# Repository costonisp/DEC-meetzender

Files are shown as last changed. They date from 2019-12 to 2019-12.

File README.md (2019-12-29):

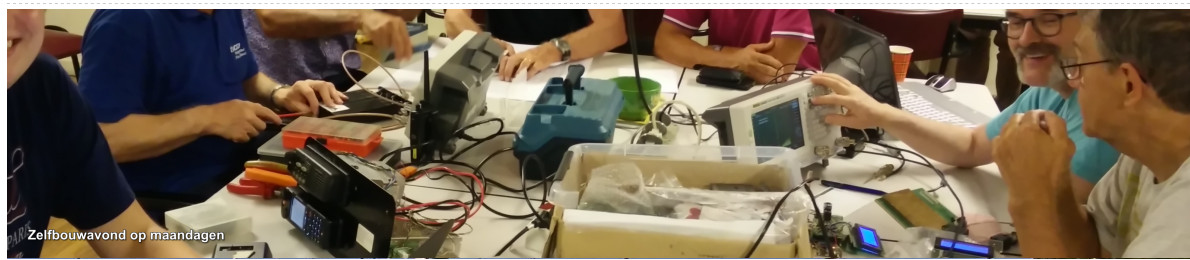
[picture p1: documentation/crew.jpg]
(https://www.pi4dec.nl/zelfbouw-meetzender/)

DEC meetzender met Si5351, en 150dB verzwakker, ontworpen door en voor **DEC Dordrecht**

Meeste aktieve bijdragen zijn geleverd door:

 - **Arnold PB0AIC :**  alle ontwerpen en printontwerpen voor: verzwakker, besturing en oscillator-I2C interface
 - **Mart PH0MH :** behuizing, draaibankwerkzaamheden voor oscillator behuizing en afscherming van de verzwakker.
 - **Arie PA3A :** software ontwerp.
 - **Coos PA0OOO :** software, co-ontwerp besturingsprint, documentatie.

__[Source Code](SourceCode/source_code.md)__

__[Besturings print](documentation/besturings_print.md)__

__[Verzwakker print](documentation/verzwakker_print.md)__

__[Si5351 oscillator + I2C isolator](documentation/Si5351%2Binterface.md)__

__[Behuizing](/documentation/behuizing.md)__

[**.**](https://github.com/costonisp/A/blob/master/node.md)

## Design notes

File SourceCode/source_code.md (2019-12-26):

__[SourceCode folder-view](/SourceCode)__

    Eenvoudigste is om de (meest recente) zipfile hieronder aan te klikken. 
    De [download] knop staat dan aan de rechter-zijde, naast de [history] knop.
    Plaats de uitgepakte zip-file in de Arduino sketch folder, waarna het compileren
    en uploaden naar een Mega2560 eenvoudig moet lukken.

    Zorg er wel voor dat een recente versie van de "Etherkit Si5351 by Jason Milldrum"  geinstalleerd is.

__[**Versie 3112.zip** : ](/SourceCode/Meetzender_v3112.zip)__ (december 2019)

   [Handleiding v3112](Handleiding3112.txt)
   
    Deze versie ondersteund diverse menu's, waardoor een verhoogd gebruiksgemak.
    Via menu kan een correctiefactor worden ingevoerd waarmee de afwijking van het 
    referentie Xtal op de oscillator module kan worden gecorrigeerd.
    Instelbaar Hamband menu, keuze van voorgeprogrammeerde frekwenties/golflengtes.
    Instelbare harmonische factor die de maximale aangegeven frekwentie bepaalt.
    Voor het geval dat 0dBm uitgangsvermogen te laag is kan via een menu tijdelijk 
    het uitgangsvermogen verhoogd worden tot ca +12 dBm. (Drive 2, 4, 6 of 8 mA)

__[Versie 085 CLK1 dec.zip : ](/SourceCode/Meetzender_0_85_CLK1_dec.zip)__(2018)

    >Deze versie is versie 085 aangepast aan de recente besturingsprint.
    Het signaal staat op CLK1, de middelste SMA connector.
    LCD display gebruikt pin 44 en 46, daardoor is pin 50 t/m 53 bruikbaar als SPI bus.

__[Versie 085.zip : ](/SourceCode/Meetzender_0_85.zip)__(2017)

    Dit is de oorspronkelijke versie geschreven door Arie PA3A.
    Werkt niet meer met de meest recente besturingsprint.
    LCD display gebruikt Arduino pin 50 en 52, waardoor de SPI bus geblokkeerd is.

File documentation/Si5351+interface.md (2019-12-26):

[//]: # (Table-A with 3-columns/5-lines, table-B with 2-columns/1-line)

## Si5351 Oscillator Board met  Bidirectionele Dual I2C Isolator:

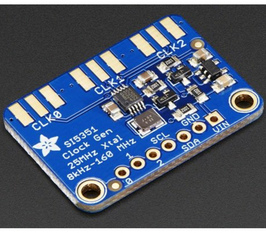
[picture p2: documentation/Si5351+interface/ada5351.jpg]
 | 
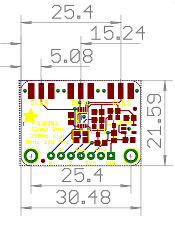
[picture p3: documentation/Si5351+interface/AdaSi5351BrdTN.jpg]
 | 
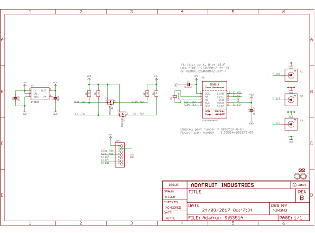
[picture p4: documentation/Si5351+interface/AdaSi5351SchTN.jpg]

--- | --- | ---
**Si5351 oscillator board** | **board layout** | **schema Si5351 board**
  |   | 
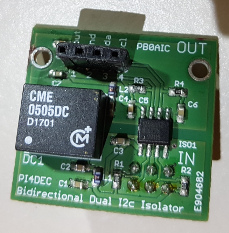
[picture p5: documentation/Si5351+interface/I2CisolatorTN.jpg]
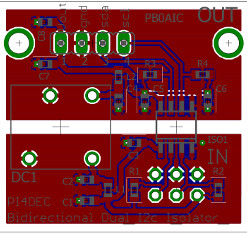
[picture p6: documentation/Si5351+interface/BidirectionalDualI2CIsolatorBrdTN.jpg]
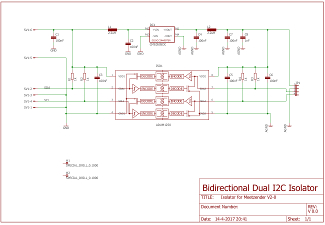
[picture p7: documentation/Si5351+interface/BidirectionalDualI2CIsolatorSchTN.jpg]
 |   | 
**I2C isolator board**  | **board layout** | **schema dual I2C isolator**

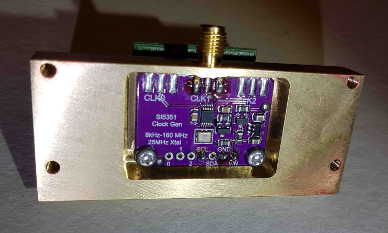
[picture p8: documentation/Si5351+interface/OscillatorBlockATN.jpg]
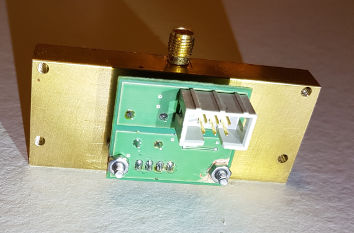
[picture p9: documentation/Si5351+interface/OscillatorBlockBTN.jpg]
 | 
---- | ----
 **Oscillator board in messing behuizing** | **I2C board op achterzijde behuizing**

Het AdaFruit Si5351 oscillator-board is in een massief messing blok gemonteerd en dit word op de messing afscherming van de verzwakker print geschroefd. 
Aan de achterkant van de oscillator-module is het I2C Isolator board gemonteerd. 
Om hf-lekkage te vermijden is dit board van eigen DC-DC converter voorzien. De I2C isolatie is met een <a href="Si5351+interface/ADUM1250_1251.pdf"> ADUM1250 </a> isolatorIC .
 
De oscillator module word met een bandkabel op de besturingsprint aangesloten.

Met een semi-rigid RG402 coax-kabel is de oscillator module op de verzwakker module aangesloten.
Daardoor kan het signaal niet via I2C, voedings leiding of door een niet volledig hf-dichte coax naar buiten lekken.
Op deze manier is het mogelijk om het signaal tot -145dBm te verzwakken.

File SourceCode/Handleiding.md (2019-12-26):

Coos, [18.12.19 20:46]
Gebruiksaanwijzing voor de meetzender software V.3012

**********************************
*
* -------- Display -----------
* regel1: f=  432.260.000 kHz
* regel2:  3e harmonic -9.5 dB
* regel3: L= - 73 dBm  xxxxxxx 
* regel4:      50  uV S9 + 0dB
* ----------------------------
*
*
*         Draaischakelaars:
*    S1         S2         S3
*   Level      N.C.    Frekwentie
*
*
*           Drukknoppen:
*   S4      S5      S6      S7 
* Store    Get   HamBand  Config
* waarde  waarde   Menu    Menu
*
**********************************

(dubbel)Functies van de knoppen:

S1 draaien om verzwakking in te stellen, op regel3,
   regel4 geeft de uitgangsspanning in mV, uV of nV 
   en de S-schaal van  S9+73dB tot S0-23dB
   drukken keuze 0, -33, -73, -109, -127, -140 dB

S3 draaien voor continue frekwentie instellen
   drukken onm de digit (stap) te kiezen

S4 Store waarde, slaat level en Frekwentie op in EEprom 

S5 Get waarde, haal opgeslagen Level en Frekwentie uit EEprom

S6 HamBand Menu, Met S3 draaiknop kies je een HamBand

S7 Dubbele functie, kort drukken kom je in het configuratie menu
   Lang drukken (>3 seconden) een soft reset indien nodig.

Configuratie Menu, met S3 draaiknop de optie kiezen
1: calibratie xxx  ppm
2: Si5351 fMax <150 MHz
3: Harmonic factor 3-15
4: Drive Output 2,4,6,8 mA
5: Zet waarden in EEprom
   Met S1 de optie bevestigen en draaien voor waarde veranderen.
   Opnieuw S1 op de waarde te bevestigen.

1: calibreren van het 25MHz referentie Xtal 
Calibratie van het referentie Xtal frequentie, correctie in ppm
S1 drukken en dan met S1 de correctiewaarde instellen
S1 opnieuw drukken om de waarde te bevestigen

2: Si5351 fMax
Default waarde is 150MHz, kan met 25MHz stappen tot 300MHz.
N.B. door een beperking van de etherkit library kan bij frekwenties
vanaf 150 MHz de output willekeurig uitvallen, deze optie is voor test.
Met S1 kiezen en bevestigen.

3: Harmonic factor naar keuze 1, 3e, 5e, 7e, 9e, 11e, 13e, 15e
Te activeren met S1, draaien voor waarde en opnieuw S1 drukken om te bevestigen.
Bij 1 kan de meetzender tot 150MHz, met 3 tot 450 MHz enz.
1e-150 / 3e-450 / 5e-750 / 7e-1050 / 9e-1350 / 11e-1650 / 13e-1950 / 15e-2250MHz
Indien van toepassing staat op regel 2 de harmonische met de correctie.
Harmonischen van een blokgolf zijn minder sterk dan de grondgolf.
3e harminische is 1/3 in spanning, wat gelijk staat aan -9.5dB
5e=-14dB  7e=-17dB  9e=-19dB 11e=-21dB 13e=-22.5dB 15e=-23.5dB
N.B. deze waarden zijn afgerond op 0.5dB (onnauwkeurigheid +/-0.25dB
Deze waarde moet van de aangegeven waarde afgetrokken worden om het juiste niveau v/d harmonische te berekenen. 
B.v. L=-33dB en 3e harm=-9.5, dan is niveau (-33 -9.5) = -43.5dB. 
De grondtoon is ook aanwezig op -33dB, net als alle harmonischen aanwezig zijn met een afnemend niveau.
Dat is onvermijdelijk met een ongefilterde blokgolf.
 
4: Si5351 Drive Output kan ingesteld worden, default waarde = 2mA. 
Daarop is de meetzender geijkt. Tijdelijk kan er een grotere Drive output gekozen worden, op regel 3 bij xxxx wordt de correctie waarde in dB gezet.
4 mA = +3dB / 6 mA = + 9.5 dB / 8 mA = +12 dB op te tellen bij het niveau

5: Zet waarden in EEprom
Door S1 te drukken staat op regel 3 Level knop opslaan en regel 4 annuleren andere knop,
Door opnieuw S1 te drukken worden de Referentie correctie (ppm) en de harmonische opgeslagen in EEprom. 
Drive mA en fMax van Si5351-chip worden niet opgeslagen, zodat bij een koude start of reset de Maximale frekwentie 150 MHz is en de Drive 2 mA bedraagt.

Opnieuw drukken van S7, verlaat het configuratie menu.

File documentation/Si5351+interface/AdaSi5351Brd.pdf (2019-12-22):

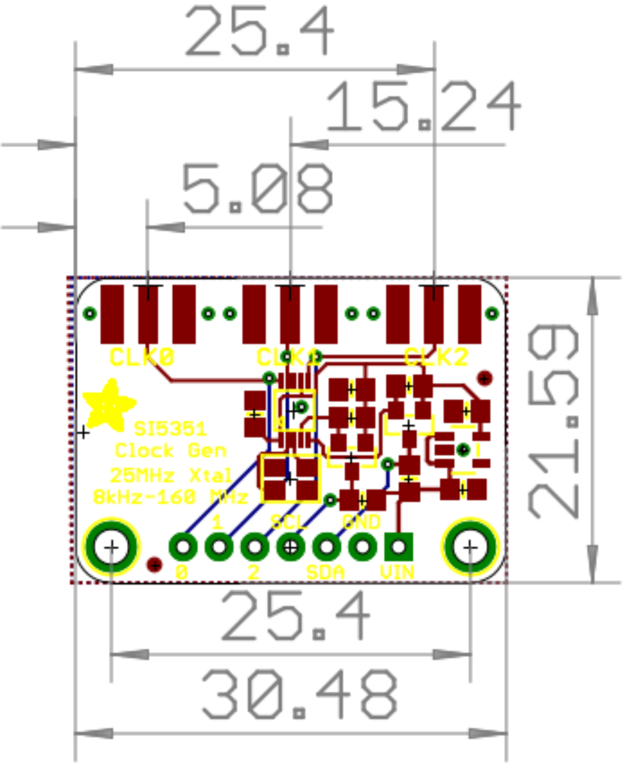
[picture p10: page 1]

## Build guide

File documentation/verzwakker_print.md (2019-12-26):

## VERZWAKKER PRINT :

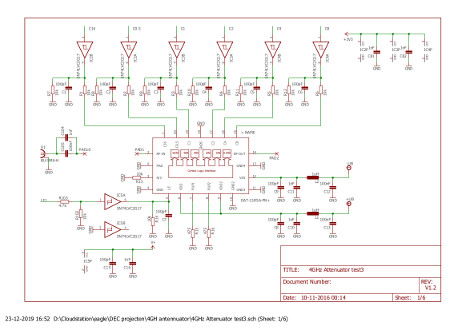
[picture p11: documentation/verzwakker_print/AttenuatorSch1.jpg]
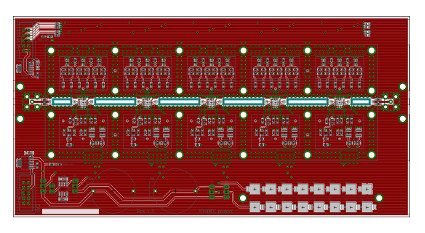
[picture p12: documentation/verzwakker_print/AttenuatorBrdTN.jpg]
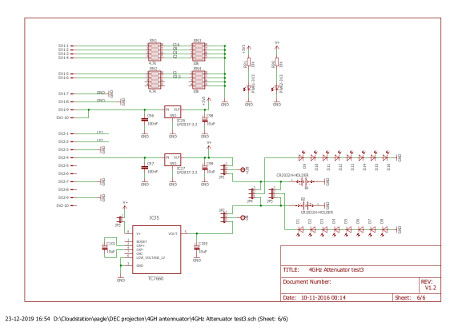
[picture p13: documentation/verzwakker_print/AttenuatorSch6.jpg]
 |     |     
--------------------------------------------- | --- |  --------------------------------------------
**5x Digitale stap verzwakker** | **Board layout**  | **Power Supply verzwakker**
|  | 
|  |

De verzwakker module bestaat uit 5 identieke deelverzwakkers. Iedere deelverzwakker bestaat uit een [DAT-31R5A-PN](verzwakker_print/DAT-31R5A-PN.pdf)  digitale stap verzwakkers van Mini Circuits met daarbij behorende stuur logica. Ieder IC met componenten zit op het PCB in een eigen omgeving. Als afscherming dienen twee uitgefreezde messing platen die boven en onder over de PCB gemonteerd worden. Daardoor ontstaan 5 kleine rf-dichte kamertjes. De koppeling tussen de 5 verzwakkers gebeurt met kleine stukjes 50 ohm RG402 kabel.

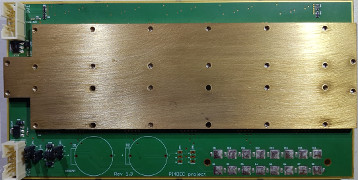
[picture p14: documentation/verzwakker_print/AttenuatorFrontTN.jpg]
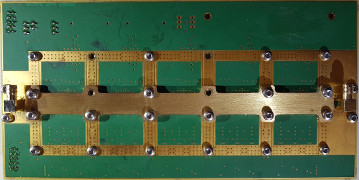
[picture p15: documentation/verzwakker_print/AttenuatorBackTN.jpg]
 |    

Een enkele verzwakker is 6-bit met een resolutie van 0.5dB, zodat per chip max -31.5dB is in te stellen. Met 5 deelverzwakkers in serie kan zodoende maximaal -157.5dB ingesteld worden. In de praktijk blijkt dat de bruikbare grens bij 145dB verzwakking ligt. Dit wordt veroorzaakt doordat een zeer klein deel van het rf-signaal toch weg kan lekken

De verzwakker kan tot minstens 3000 MHz goed werken. Voor de meetzender ligt de praktische grens iets boven 1000 MHz.
Dit komt door de schakeltijden in de Si5351 oscillator die een blokgolf produceerd waarbij harmonischen worden gebruikt om boven 150 Mhz te komen. De 150 MHz wordt bepaald door de etherkit library, die boven 150 MHz onvoorspelbaar gedrag vertoond, de Si5351 chip zelf kan tot ca. 250 MHz stabiele signalen geven

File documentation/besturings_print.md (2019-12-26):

[//]: # (Table with 3-columns/7-lines)

## BESTURINGS PRINT :

De Besturingsprint is een 4-laags PCB. 
De signaal verbindingen liggen opgesloten tussen een massa vlak en een Vcc vlak, zodat stoorstraling geminimaliseerd wordt.

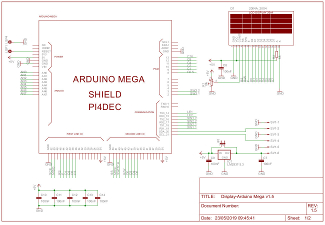
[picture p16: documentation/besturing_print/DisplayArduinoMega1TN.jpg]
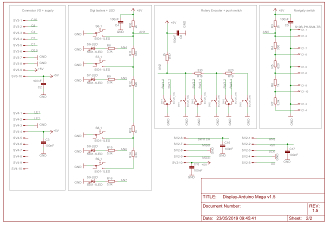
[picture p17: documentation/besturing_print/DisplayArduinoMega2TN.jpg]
 | **+** |  
--------------------------------------------- | --- |  -----------------------------------------------
**ArduinoMega2560 + Display + I2C-connector** |     | **Drukknoppen + Rotary schakelaars + connectors**
  |     |  
  |     | 
  |     | 
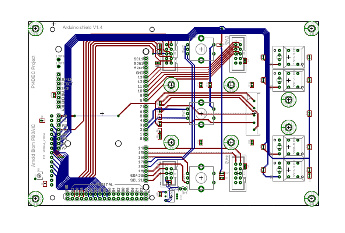
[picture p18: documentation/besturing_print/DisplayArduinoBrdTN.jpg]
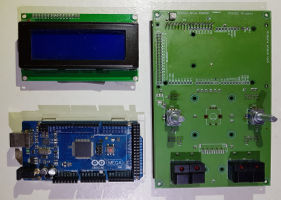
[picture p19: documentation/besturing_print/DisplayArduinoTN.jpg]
 |**-** | 
  **PCB layout** *( inner layers )* |     |   **module's v/d besturingsprint**
  
**Headers :** voor een full-size Arduino Mega 2560

**Header  :** voor een Display LCD2004

**Boxed Headers :**

 -  SV1 :  6-polig connector (sda-scl) + voeding voor dual I2C isolator board
 -  SV2 : 10-polig connector + voeding van SPI-bus
 -  SV3 : 10-polig data stuursignaal verzwakker print
 -  SV4 : 10 polig latch stuursignaal verzwakker print

**Schakelaars :**

 -  tact-switches:  S6, S7, S8 en S9  met Led's
 -  rotary-swiches: SW1 en SW2  met drukschakelaar S1 en S2

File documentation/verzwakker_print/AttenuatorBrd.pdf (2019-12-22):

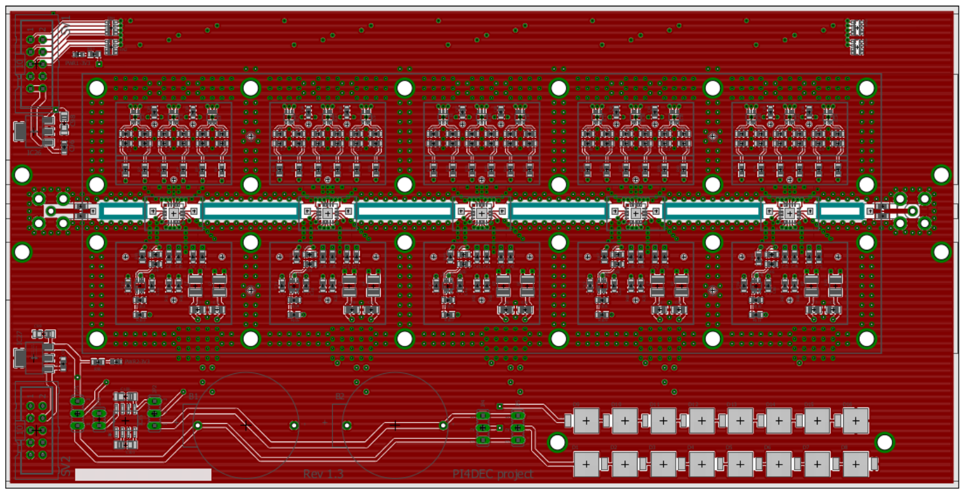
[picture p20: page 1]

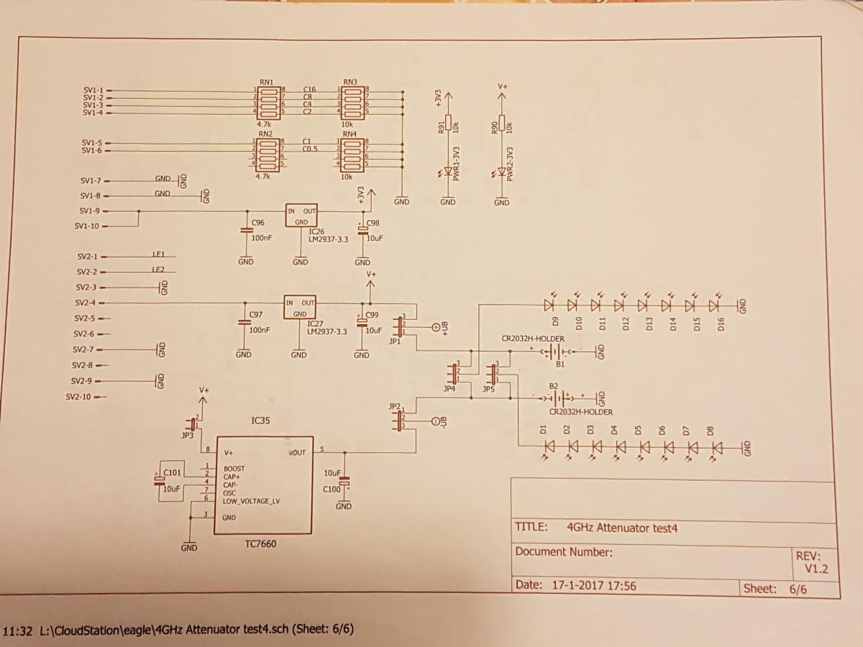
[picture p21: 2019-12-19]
documentation/verzwakker_print/AttenuatorPower.jpg

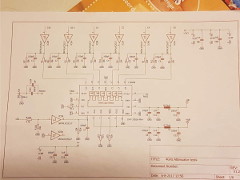
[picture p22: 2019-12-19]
documentation/verzwakker_print/AttenuatorTN.jpg

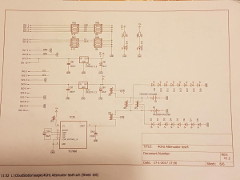
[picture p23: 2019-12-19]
documentation/verzwakker_print/AttenuatorPowerTN.jpg

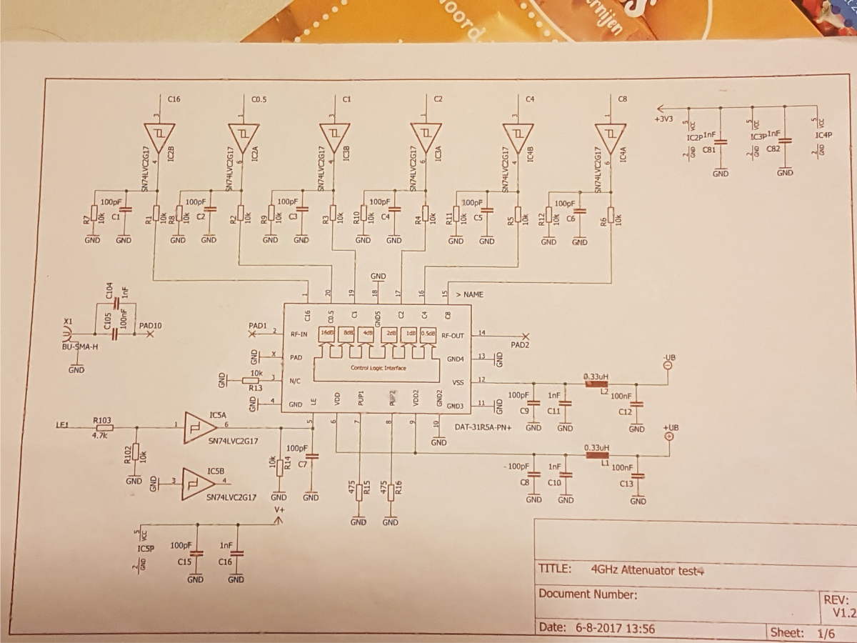
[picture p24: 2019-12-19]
documentation/verzwakker_print/Attenuator.jpg

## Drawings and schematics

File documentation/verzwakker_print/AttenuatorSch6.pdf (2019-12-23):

# GND ¹⁰k

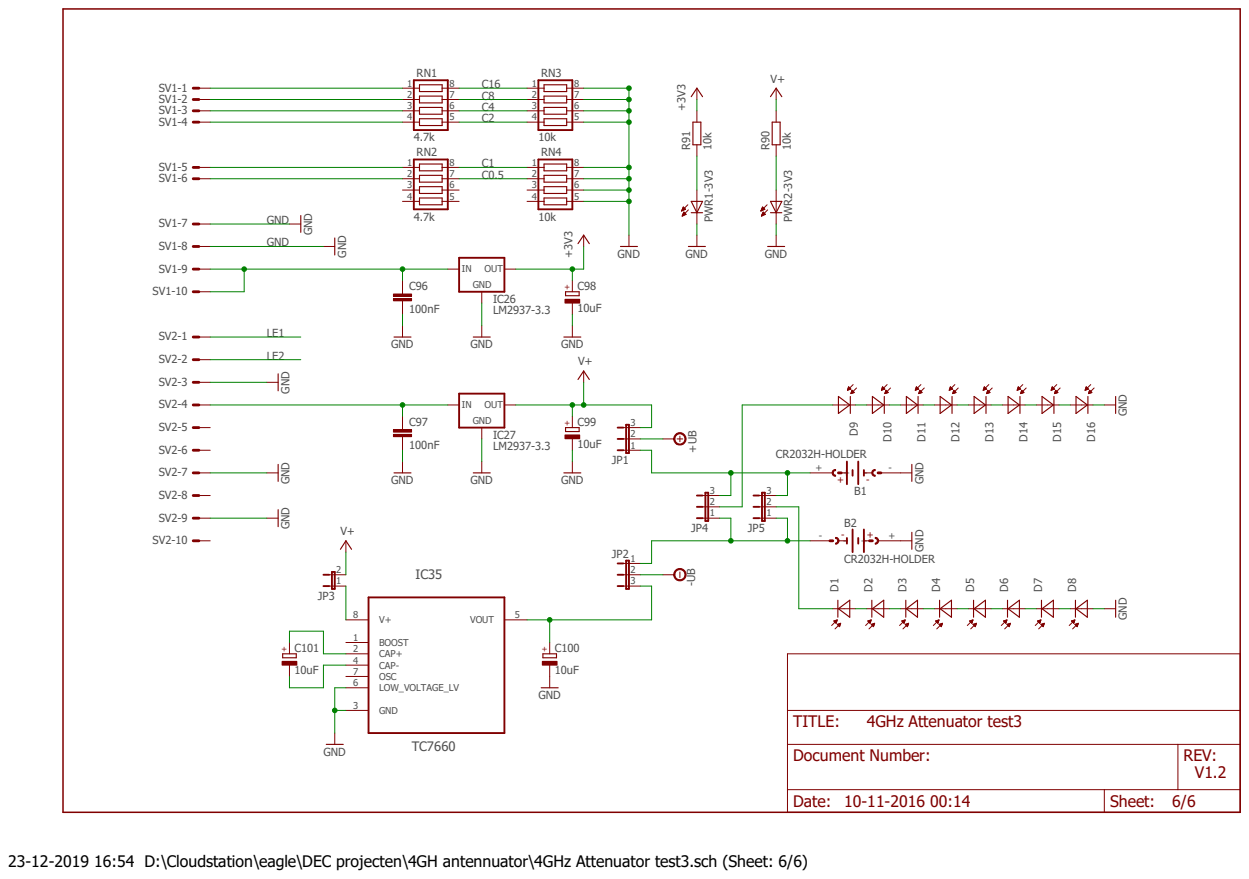
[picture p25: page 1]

7 C8 2 | 7
6 C4 3 | 6

7 C0.5 2 | 7

Document Number: | REV: V1.2

Date: 10-11-2016 00:14 | Sheet: 6/6

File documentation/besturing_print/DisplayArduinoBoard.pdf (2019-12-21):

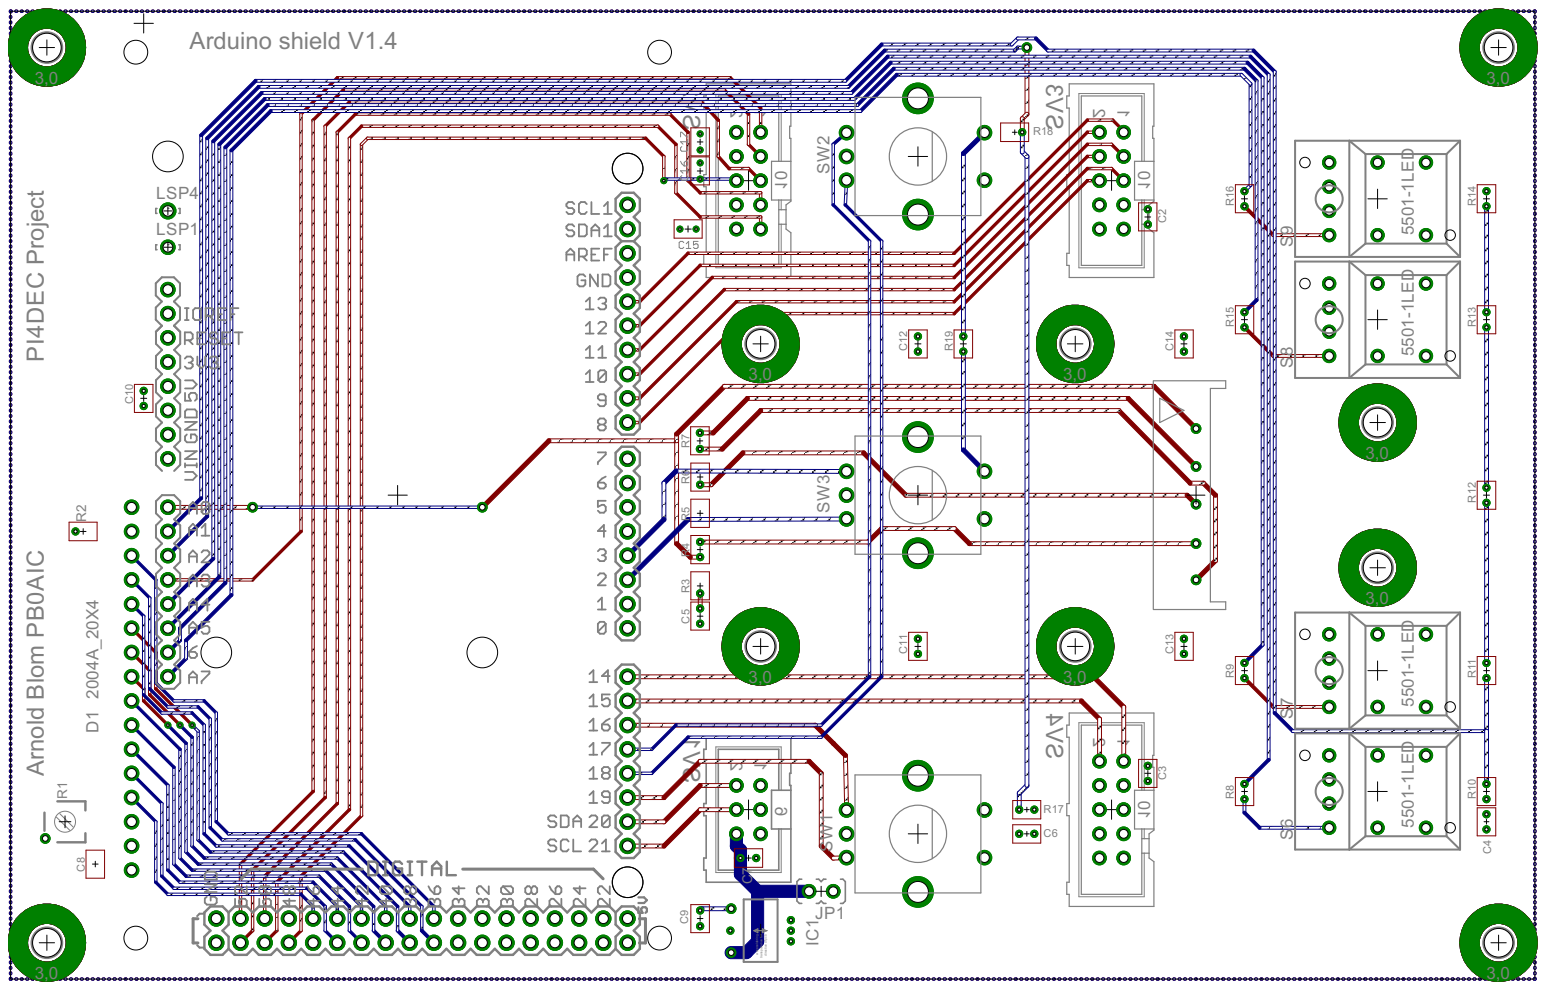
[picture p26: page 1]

SV3 SV4 SV1 SV2 10 21 10 21 21 6 10 21 Arduino shield V1.4 Arnold Blom PB0AIC PI4DEC Project D1 R2 SW1 SW2 SW3 R3 R4 R5 R6 R7 S6 S7 R8 R9 R10 R11 R12 R13 R14 S8 S9 R15 R16 R1 R17 R18 C2 C3 C4 C5 C6 C C7 8 LSP1 LSP4 IC C19 C10 C11 C12 C13 C14 JP1 R19 2004A_20X4 5501-1LED 5501-1LED 5501-1LED 5501-1LED 3,0 3,0 3,0 3,0 3,0 3,0 3,0 3,0 3,0 3,0 direction of pcb transportation for wavesoldering

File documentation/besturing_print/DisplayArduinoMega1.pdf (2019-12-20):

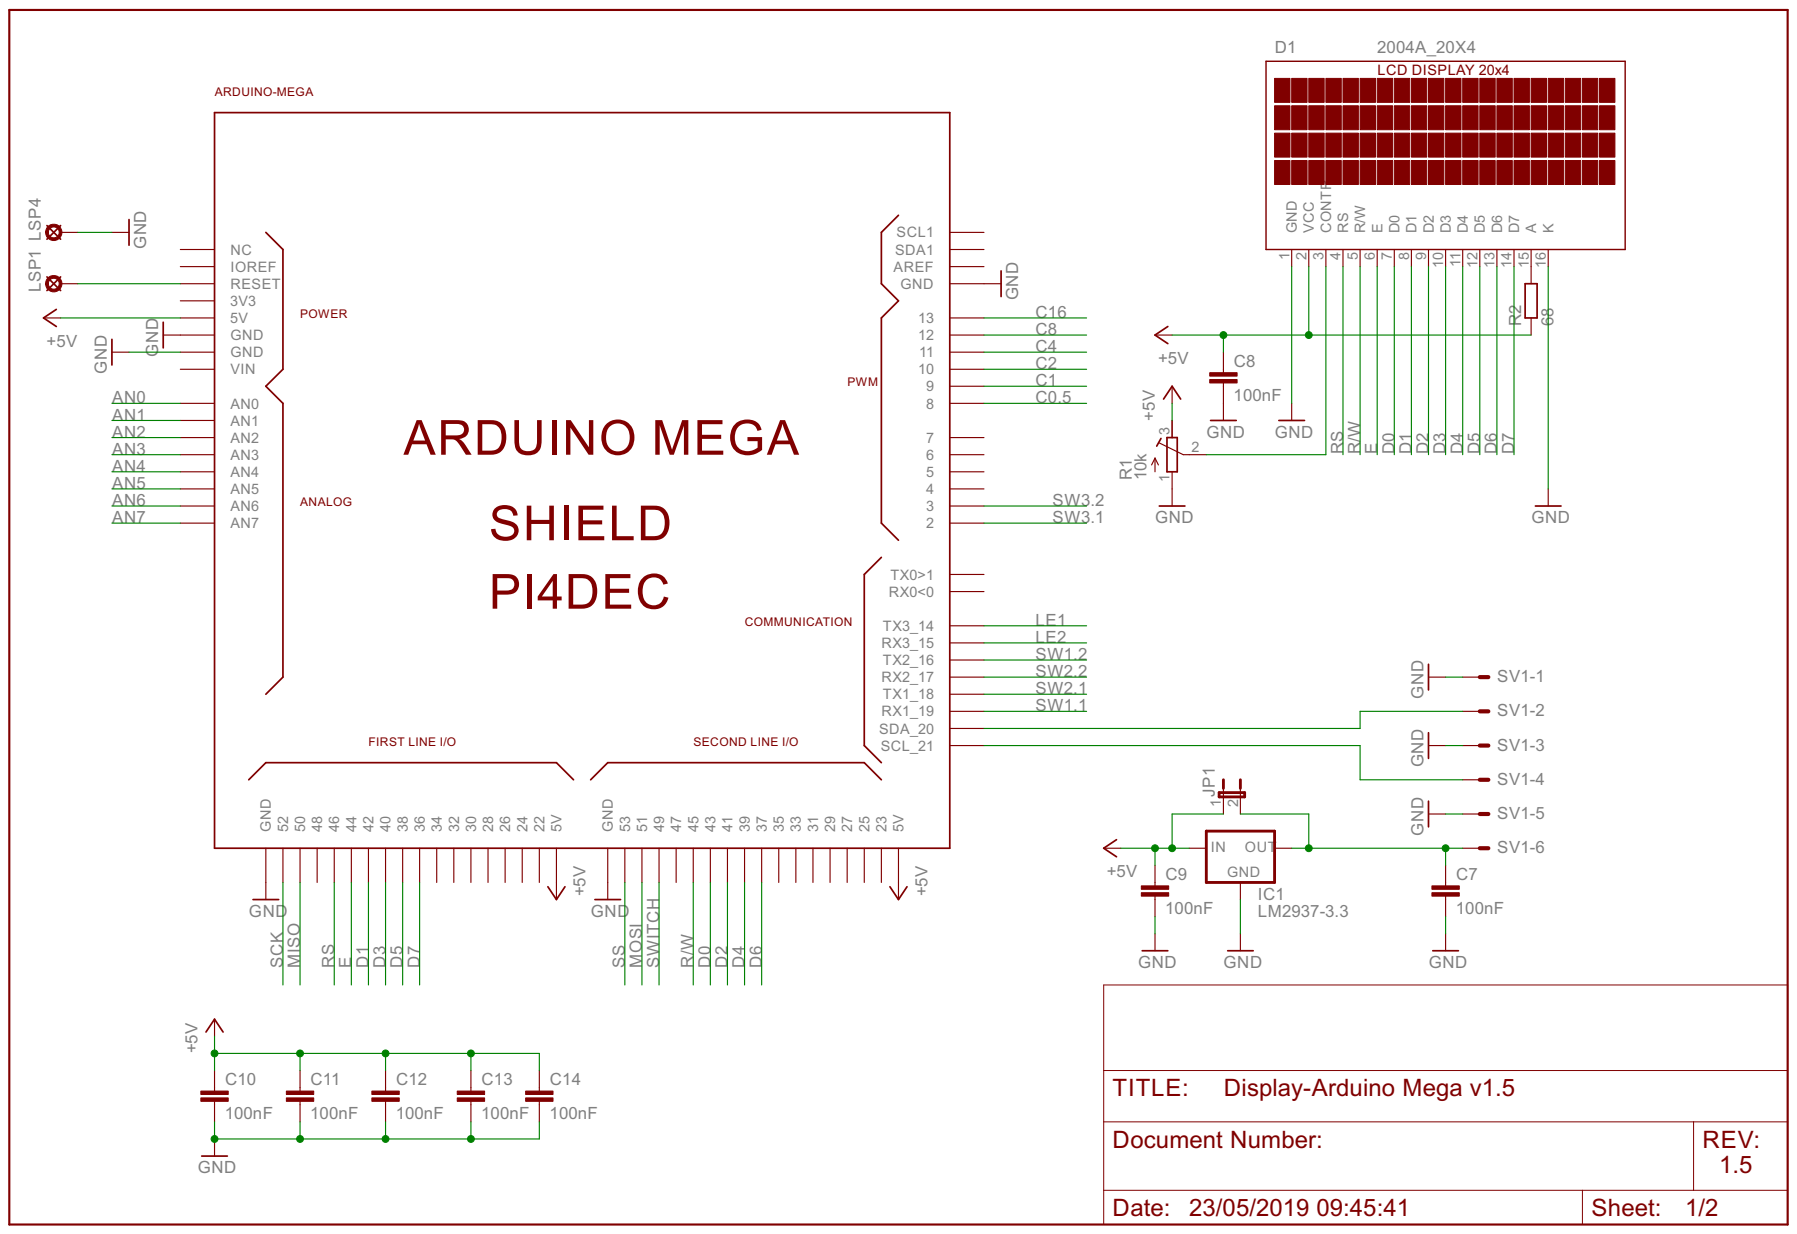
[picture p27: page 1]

LCD DISPLAY 20x4 ARDUINO MEGA

Document Number: | REV: 1.5

Date: 23/05/2019 09:45:41 | Sheet: 1/2

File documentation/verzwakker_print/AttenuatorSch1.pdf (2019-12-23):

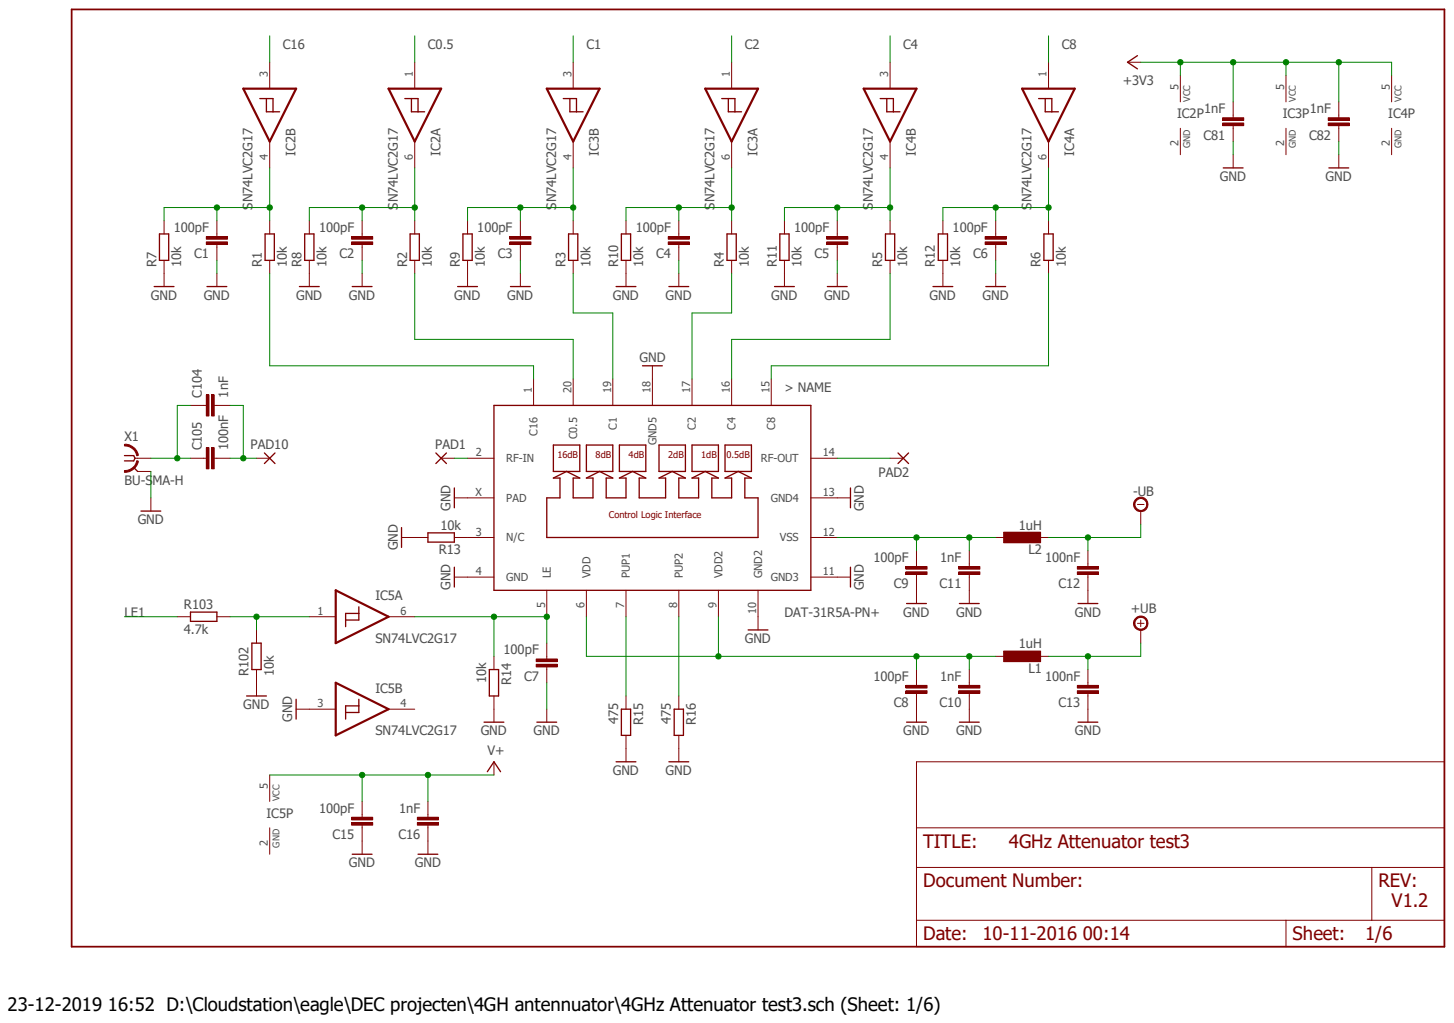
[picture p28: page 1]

Document Number: | REV: V1.2

Date: 10-11-2016 00:14 | Sheet: 1/6

23-12-2019 16:52 D:\Cloudstation\eagle\DEC projecten\4GH antennuator\4GHz Attenuator test3.sch (Sheet: 1/6)

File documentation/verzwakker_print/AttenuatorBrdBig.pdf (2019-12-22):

22-12-2019 22:29 f=1.40 D:\Cloudstation\eagle\DEC projecten\4GH antennuator\4GHz Attenuator test3.brd ¹⁰

## PWR1-3V3

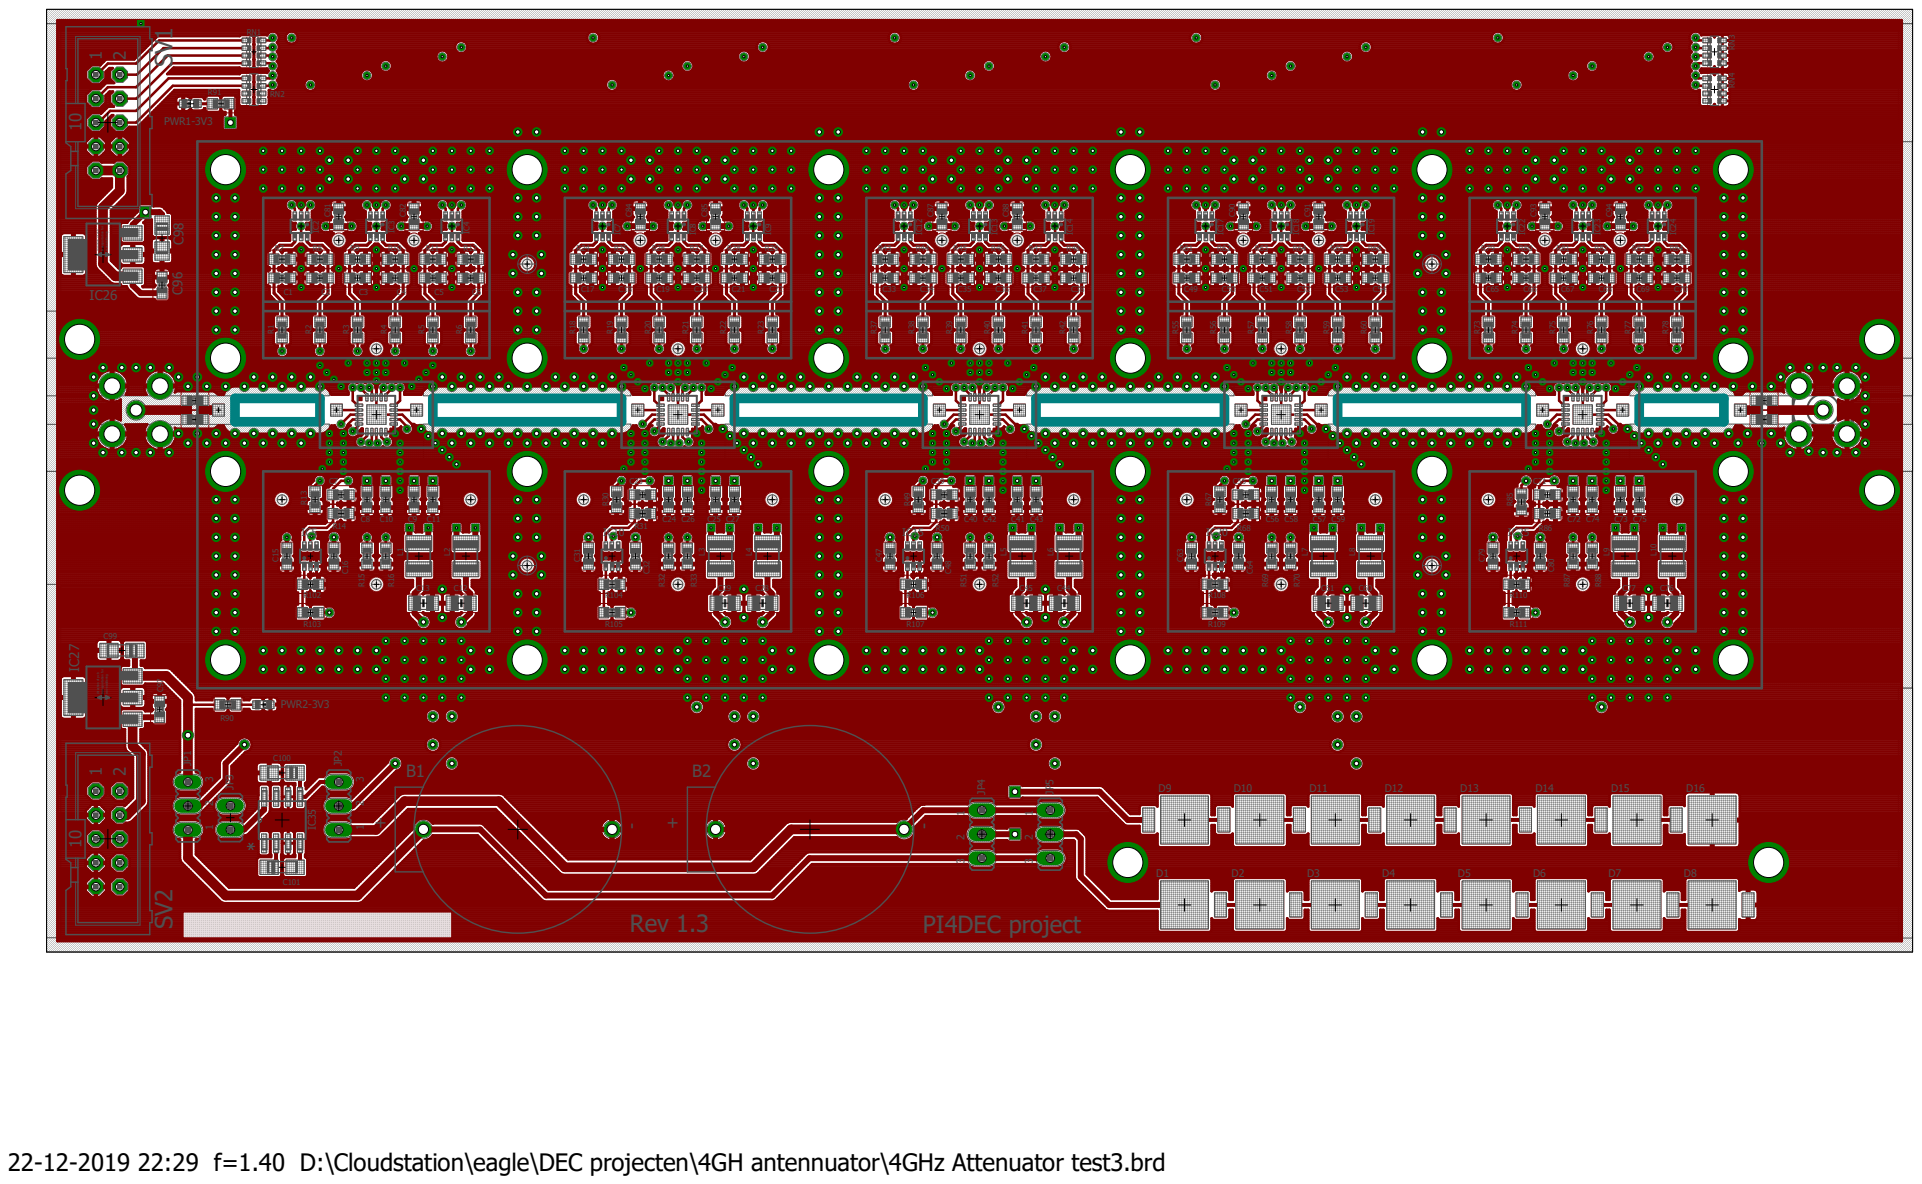
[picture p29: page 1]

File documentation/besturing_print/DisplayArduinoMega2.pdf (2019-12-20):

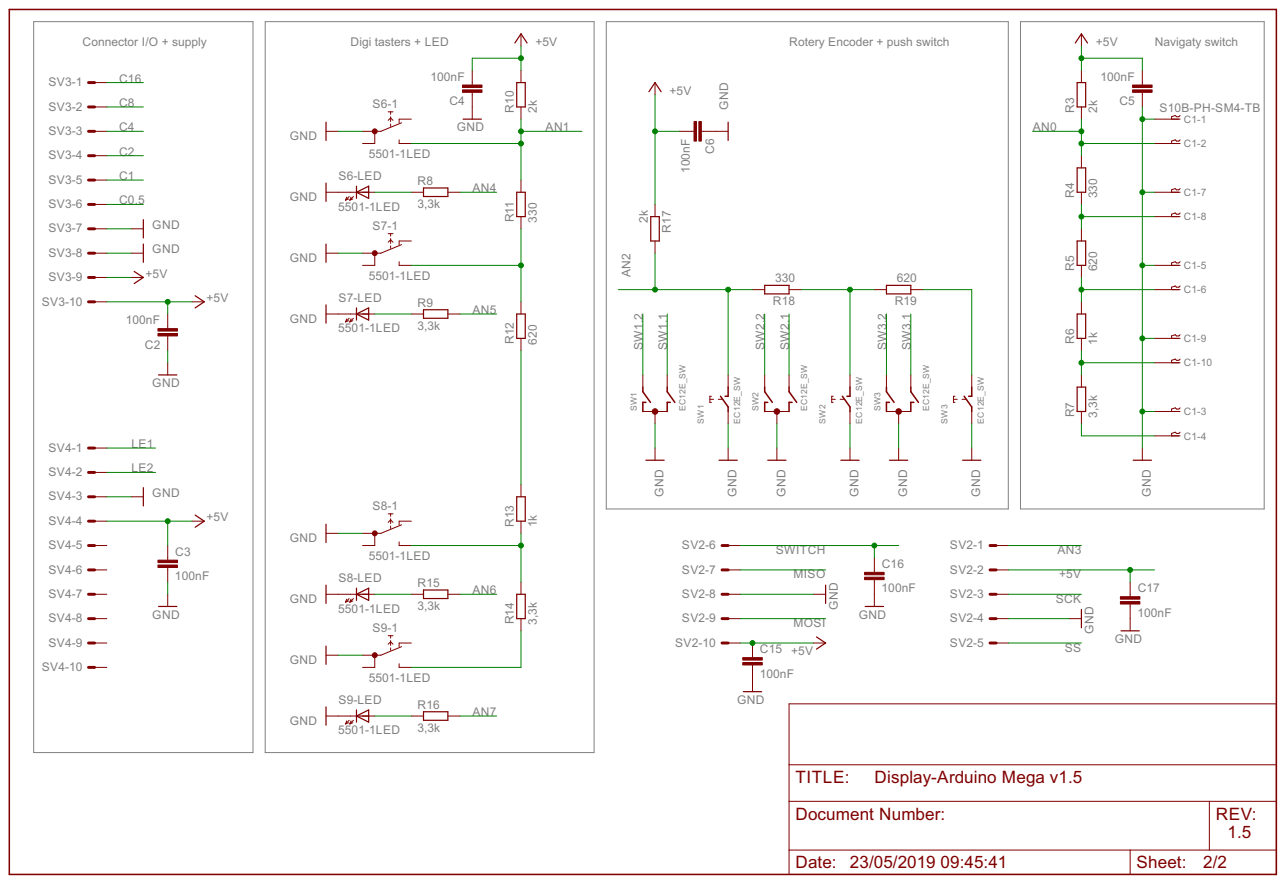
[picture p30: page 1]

Document Number: | REV: 1.5

Date: 23/05/2019 09:45:41 | Sheet: 2/2

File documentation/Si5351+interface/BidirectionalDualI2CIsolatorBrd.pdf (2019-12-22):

## PB0AIC OUT

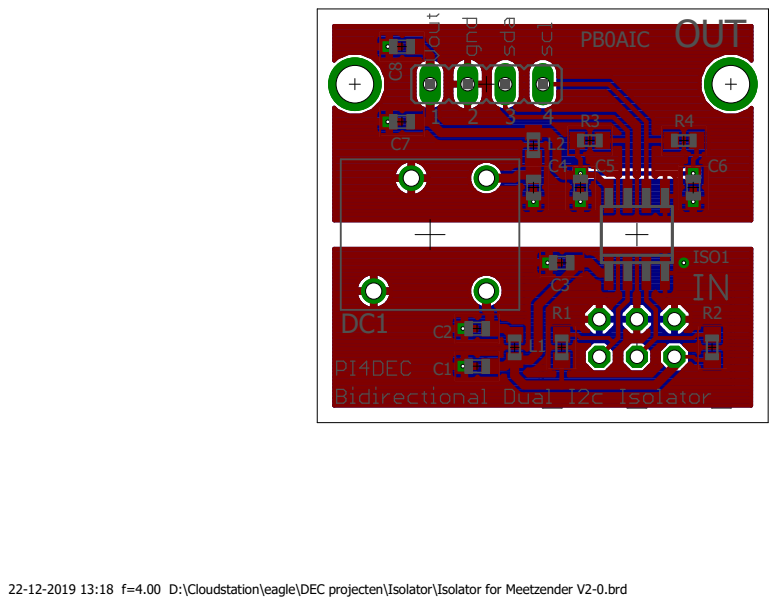
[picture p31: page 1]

22-12-2019 13:18 f=4.00 D:\Cloudstation\eagle\DEC projecten\Isolator\Isolator for Meetzender V2-0.brd

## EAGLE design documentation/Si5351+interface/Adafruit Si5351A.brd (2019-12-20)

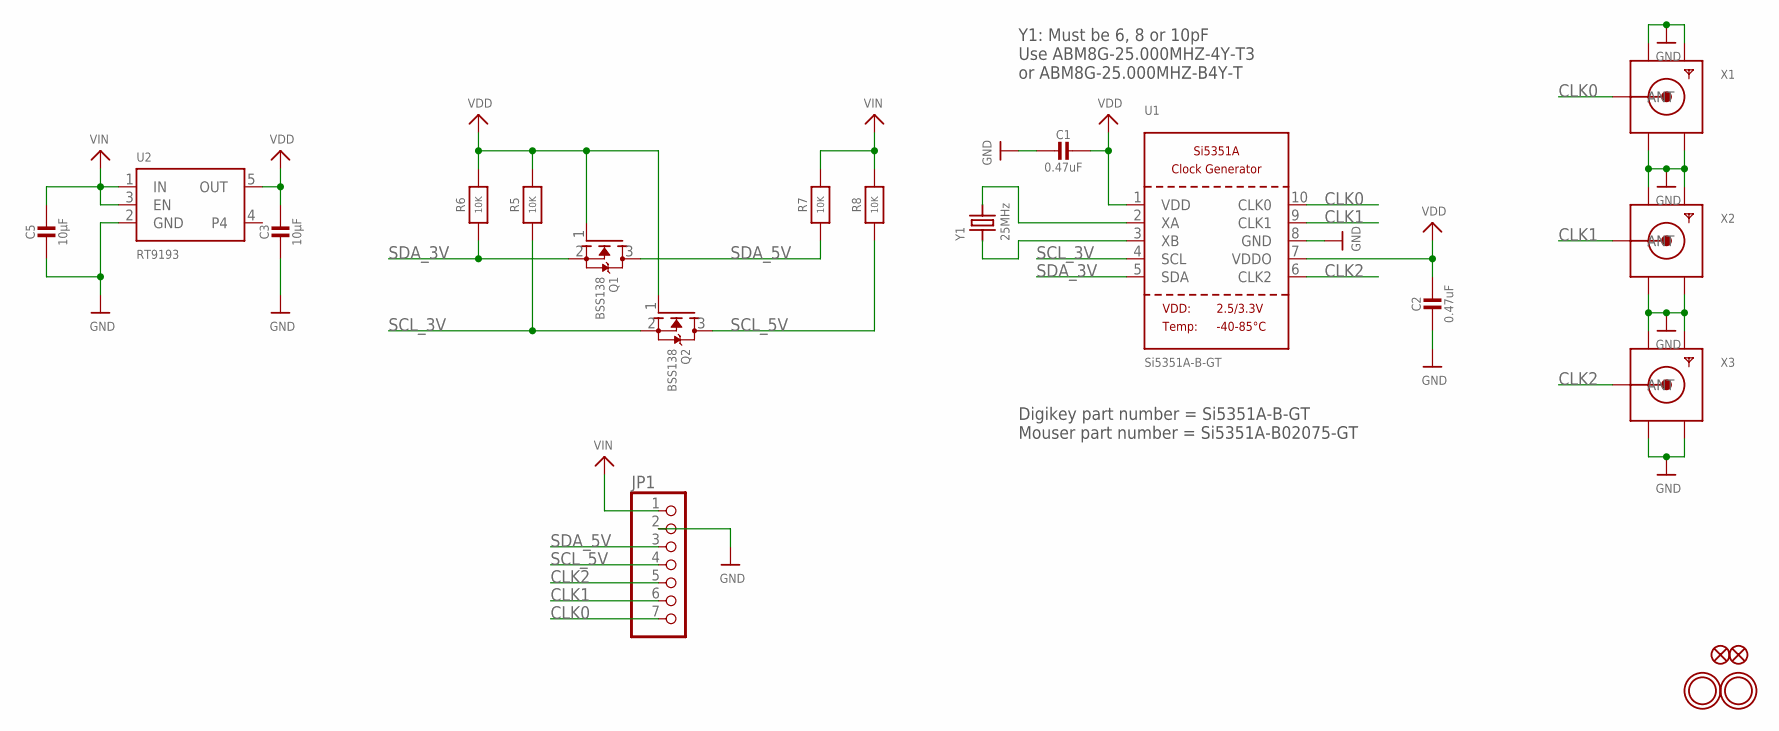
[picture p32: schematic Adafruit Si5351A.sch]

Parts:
C1, C2: 0.47uF; 0805-NO
C3, C5: 10µF; 0805-NO
FID1, FID2: FIDUCIAL""; FIDUCIAL_1MM
JP1: HEADER-1X7THICKER; 1X07_ROUND_76
Q1, Q2: BSS138; SOT23-WIDE
R5, R6, R7, R8: 10K; 0805-NO
U1: Si5351A-B-GT; MSOP10
U2: RT9193; SOT23-5
U$10, U$11: MOUNTINGHOLE2.5; MOUNTINGHOLE_2.5_PLATED
X1, X2, X3: SMACONNECTOR_EDGE; SMA_EDGELAUNCH
Y1: 25MHz; CRYSTAL_3.2X2.5

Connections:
CLK0: JP1.7, U1.10 (CLK0), X1.P (ANT)
CLK1: JP1.6, U1.9 (CLK1), X2.P (ANT)
CLK2: JP1.5, U1.6 (CLK2), X3.P (ANT)
GND: C1.2, C2.2, C3.2, C5.2, JP1.2, U1.8 (GND), U2.2 (GND), X1.GND@1 (GND4), X1.GND@2 (GND3), X1.GND@3 (GND2), X1.GND@4 (GND1), X2.GND@1 (GND4), X2.GND@2 (GND3), X2.GND@3 (GND2), X2.GND@4 (GND1), X3.GND@1 (GND4), X3.GND@2 (GND3), X3.GND@3 (GND2), X3.GND@4 (GND1)
unnamed: U1.3 (XB), Y1.1
unnamed: U1.2 (XA), Y1.2
SCL_3V: Q2.2 (S), R5.1, U1.4 (SCL)
SCL_5V: JP1.4, Q2.3 (D), R8.1
SDA_3V: Q1.2 (S), R6.1, U1.5 (SDA)
SDA_5V: JP1.3, Q1.3 (D), R7.1
VDD: C1.1, C2.1, C3.1, Q1.1 (G), Q2.1 (G), R5.2, R6.2, U1.1 (VDD), U1.7 (VDDO), U2.5 (OUT)
VIN: C5.1, JP1.1, R7.2, R8.2, U2.1 (IN), U2.3 (EN)

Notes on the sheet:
Digikey part number = Si5351A-B-GT Mouser part number = Si5351A-B02075-GT
Y1: Must be 6, 8 or 10pF Use ABM8G-25.000MHZ-4Y-T3 or ABM8G-25.000MHZ-B4Y-T

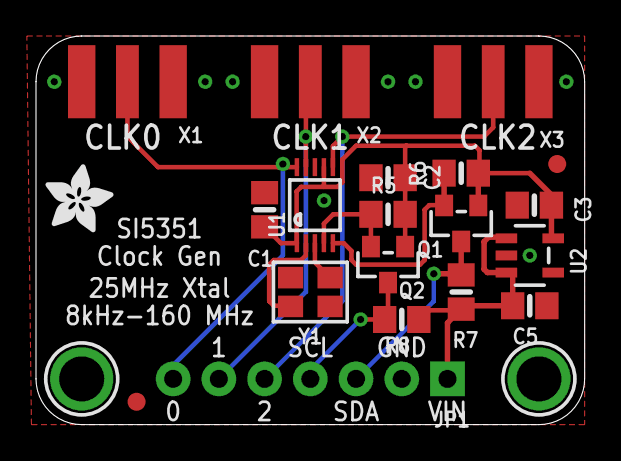
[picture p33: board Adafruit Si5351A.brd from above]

Board: 2 copper layers, 30.5 x 21.6 mm, 23 parts (1 on the bottom side), 12 nets.

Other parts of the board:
U$12: ADAFRUIT_3.5MM
U$23: ADAFRUIT_TEXT_20MM

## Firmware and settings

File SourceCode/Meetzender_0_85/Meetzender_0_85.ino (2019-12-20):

/*
Deze versie is de originele versie van Arie PA3A
Deze versie is slechts voor documentatie want hij werkt niet met de huidige hardware.
Meetzender_0_85_CLK1_dec is wel bruikbaar op de huidige versie v/d besturingsprint.

De LCD display is aangesloten op pennen 50,51 en 52 {LiquidCrystal lcd(52, 50, 39,38,37,36)}
De SPI bus (pins 50,51,52 en 53) is daardoor niet beschikbaar.
*/

// ------------------------------------------------------------------------------------------------------------
//---------------------------------VERSIE 0.85 ----------------------------------------------------------------
// ------------------------------------------------------------------------------------------------------------


/* Arduino Mega 2560 kern met Encoder en Etherkit 5351 libraries
Versie 0.6 heeft een encoder voor de frequentie en een up en down toets.
Er zijn diverse funties gedefinieerd.
Versie 0.61 heeft een variabele FStep die uit de FStepArray komt. 
Versie 0.62 heeft grenzen 100 kHz - 159.999,000 MHz en hambands
Versie 0.63 heeft Hambands drukschakelaar  
Versie 0.64 met twee encoders en dBm instelling op diversie start niveaus met druk schakelaar.
Versie 0.65 schrijft netjes de SchermwaardeString (=schermwaarde) en leveldBm met punten, komma's, min teken enz.
Versie 0.66 bevat een dBm to uV functie en drukt deze af
Versie 0.67 zijn pinnen van encoder verplaatst om 2+3 vrij te maken, evenzo de display naar de dubbele rij aansluitingen,
            encoders naar: 18-17 en 19-16, displaypootjes 4,6,11,12,13,14 aan arduino 42,40,32,34,36,38
Versie 0.68 freq knop lang indrukken --> stapgrootte instellen, waren voorheen twee knoppen. die zijn nu weg. 
            S-meter waarden op de display     

Versie 0.7  Bevat een routine om de output te ijken.
            Lang en kort drukken op frq encoder: kort = verander stapgrootte, lang = verander hamband               
Versie 0.71 De 70 cm band toegevoegd als 3e harmonische
            Schermwaarde is leidend in freq verwerking, waar mogelijk is de ULL verkleind naar UL, (bv Schermwaarde is nu UL ipv ULL)
Versie 0.72 ULL variabelen hersteld. Boven een bepaalde frequentie anders geen goede data naar de VFO. Verder output power op 4mA gezet ipv 2mA
Versie 0.73 Nieuwe ATT verdeling over de verschillende chips.
Versie 0.74 Wegschrijven en ophalen LeveldBm en Schermwaarde in EEPROM, wegschrijven gebeurt met kort naar 0 halen van pin A7 (momory toets).
Versie 0.8  pins aangepast aan bedienprint versie 1
Versie 0.84 werkende versie, debugged
Versie 0.85 vertaal polynoom plaats aangegeven in funvtie en gebruikte de nieuwste 5351 bibliotheek 
*/

// ------------------------------------------------------------------------------------------------------------  
//--------------------------- Libraries -----------------------------------------------------------------------
// ------------------------------------------------------------------------------------------------------------
#include <Encoder.h>                   // rotary encoder, wordt aan interupt gehangen voor snelle reactie
#include <si5351.h>                    // voor SI5351 - dit is de etherkit library
#include <Wire.h>                      // voor I2C bus, is standaard voor Arduino
#include <LiquidCrystal.h>             // voor LCD display (is een 4 regel - 20 char display)
#include <EEPROM.h>                    // EEPROM gebruik (t.b.v. opslaan instelling bij uitschakelen)


Si5351 si5351;                         // initialiseer de Si5351 routine
                                       // LiquidCrystal(rs, e, d4, d5, d6, d7) instelling met gewone display 4x20, display pootjes: 4,6,11,12,13,14 
LiquidCrystal lcd(52, 50, 39,38,37,36); // 
Encoder FreqEnc(18,17);                // Rotary Encoder Freq aansluiting, midden aan massa (interupt op pin 18)
Encoder LeveldBmEnc(19,16);            // Rotary Encoder Level aansluiting, midden aan massa (interupt op pin 19)

//  ---------------------------------einde library zaken --------------------------------------------------------



// -----------------------------------------------------------------------------------------------------------------------------
// ---------------------------------- Variabelen -------------------------------------------------------------------------------
// -----------------------------------------------------------------------------------------------------------------------------

String Versie = "0.85";
String CALL = "PA3A";

// variabelen voor de Synth
unsigned long long Freq;                // freq voor de VFO als unsigned 64 bit getal ( =ULL ), hoogste waarde Freq = 15.000.000.000 ( te lang voor gewone unsigned long))
unsigned long long FStepArray[9] = {1,10,100,1000,10000,100000,1000000,10000000,100000000} ;
unsigned long long FStep;               // stapgrootte om te veranderen 1 Hz tot 100 MHz
unsigned long long HamBandArray[16] = {137000,475000,1860000,3560000,5360000,7060000,10120000,14060000,18080000,21060000,24920000,28060000, 50060000,70060000,144060000,432260000}; // inclusief 70cm
int HamBandIndex;
int FStepIndex ;
signed int teller;         // teller van tijd dat freqknop wordt INGEDRUKT ivm schakelen FStepIndex
int val; // hulp variabele
int valF; // hulpvariabele in Frq deel
int i; // idem
unsigned long long Schermwaarde; // wat is de gewenste freq die ook op het scherm staat


int Cursorpos[9] = {14,13,12,  10,9,8,   6,5,4}; // cursor positie in Freq uitlezing
String uVArray[151]=                             // 141 dBm waarden omgezet naar spanning incl eenheid. Simpel maar doeltreffend.
{"224  mV","199  mV","178  mV","158  mV","141  mV","126  mV","112  mV","100  mV"," 89  mV"," 79  mV"," 71  mV",
 " 63  mV"," 56  mV"," 50  mV"," 45  mV"," 40  mV"," 35  mV"," 32  mV"," 28  mV"," 25  mV"," 22  mV",
 " 20  mV"," 18  mV"," 16  mV"," 14  mV"," 13  mV"," 11  mV"," 10  mV","8,9  mV","7,9  mV","7,1  mV",
 "6,6  mV","5,6  mV","5,0  mV","4,5  mV","4,0  mV","3,5  mV","3,2  mV","2,8  mV","2,5  mV","2,2  mV",
 "2,0  mV","1,8  mV","1,6  mV","1,4  mV","1,3  mV","1,1  mV","1,0  mV","890  uV","790  uV","710  uV",
 "630  uV","560  uV","500  uV","450  uV","400  uV","350  uV","320  uV","282  uV","251  uV","224  uV",
 "199  uV","178  uV","158  uV","141  uV","126  uV","112  uV","100  uV"," 89  uV"," 79  uV"," 71  uV",
 " 63  uV"," 56  uV"," 50  uV"," 45  uV"," 40  uV"," 35  uV"," 32  uV"," 28  uV"," 25  uV"," 22  uV",
 " 20  uV"," 18  uV"," 16  uV"," 14  uV"," 13  uV"," 11  uV"," 10  uV","8,9  uV","7,9  uV","7,1  uV",
 "6,6  uV","5,6  uV","5,0  uV","4,5  uV","4,0  uV","3,5  uV","3,2  uV","2,8  uV","2,5  uV","2,2  uV", 
 "2,0  uV","1,8  uV","1,6  uV","1,4  uV","1,3  uV","1,1  uV","1,0  uV","0,89 uV","0,79 uV","0,71 uV",
 "0,66 uV","0,56 uV","0,50 uV","0,45 uV","0,40 uV","0,35 uV","0,32 uV","0,28 uV","0,25 uV","0,22 uV",
 "0,20 uV","0,18 uV","0,16 uV","0,14 uV","0,13 uV","0,11 uV","0,10 uV","0,09 uV","0,08 uV","0,07 uV",
 "0,063uV","0,056uV","0,050uV","0,045uV","0,040uV","0,035uV","0,032uV","0,028uV","0,025uV","0,022uV",
 "n.v.t. ","n.v.t. ","n.v.t. ","n.v.t. ","n.v.t. ","n.v.t. ","n.v.t. ","n.v.t. ","n.v.t. ","n.v.t. ", 
};


// variabelen voor Encoders
long oldPosition_f;  // hoort bij Freq verandering
long newPosition_f;
long newPos2_f ;

long oldPosition_L;  // hoort bij LeveldBm verandering
long newPosition_L;
long newPos2_L ;


#define UP 1
#define DOWN -1


// variabelen voor de verzwakker
signed int LeveldBm;
int Level;
int LeveldBmArray[6] = {0, -33, -73, -109, -127, -140};   // standaard levels voor S9+x, S3, S0 enz.

// aansturen van verzwakker
#define  LE1 14     // latch voor fijnregeling
#define  LE2   15   // latch voor grove 20dB stappen
#define  dB05  8    // bus pinnen 8 - 13 voor setting van verzwakkers
#define  dB1   9
#define  dB2   10
#define  dB4   11
#define  dB8   12
#define  dB16  13



// -------------------------------------------------------------------------------------------------------
// -------------------------------------------  Functies -------------------------------------------------
// -------------------------------------------------------------------------------------------------------


// -------- EEPROM funties -----------------------------------------------------

// -------- Put EEPROM functie -  Schrijft Level en Freq in de EEPROM ---------------
void PUTEEPROM(){ 
  int eeAdres=0;
  EEPROM.put(eeAdres,LeveldBm);
  eeAdres += sizeof(int);
  EEPROM.put(eeAdres,Schermwaarde);
  
}

// -------- GET EEPROM functie -  Haal Level en Freq op uit de EEPROM ---------------
void GETEEPROM() {
  int eeAdres=0;
  EEPROM.get(eeAdres,LeveldBm);
  LeveldBm--; //compenseer de startpuls van de encoder
  eeAdres += sizeof(int);
  EEPROM.get(eeAdres,Schermwaarde);
  Schermwaarde = Schermwaarde - FStep; //compenseer de startpuls van de encoder
}




// ---- Freq functies ----------------------------------------------------------

// -------------- VFO + FStep functie ---
void VFO_UP() {               
  Schermwaarde = Schermwaarde + FStep;
  if (Schermwaarde > 440000000ULL){        // Bovengrens bewaking
    Schermwaarde = 440000000ULL;
  }
  ExecFreq();                           // stuur de freq naar VFO en print op LCD
}


// --------------- VFO - FStep functie ---
void VFO_DOWN() {
  if ((Schermwaarde - FStep > 1000000000ULL) || (Schermwaarde-FStep < 100000ULL)){     // Ondergrens bewaking, is 100kHz 
    Schermwaarde = 100000ULL;             // als toekomstige Freq 'omklapt'(grote stap) of toekomstige Freq onder 100 kHz komt
  }
  else{
  Schermwaarde = Schermwaarde - FStep;
  }
  ExecFreq();                          // stuur de freq naar VFO en print op LCD
}


// ------------------ FStep veranderen met rotary encoder - functie -----
void FStepFunctie(){     // Op basis van de encoder wordt de FStep veranderd
  int valFreq = analogRead(A2);
//  Serial.println("Fstep  ");   // debugging
//  Serial.println(valFreq);
  while (valFreq <=120 || valFreq >=165)  {                  // voorheen digitalRead(A0)!=LOW) zolang de knop NIET opnieuw wordt ingedrukt..
    lcd.setCursor(Cursorpos[FStepIndex],1);
    lcd.cursor();                                       //zet de underscore (cursor) aan op positie waar de wijzigingen worden gemaakt
    lcd.blink();                                        //laat karakter op cursorplaats knipperen,
    valFreq = analogRead(A2);                           // tijdens de while do blijven scannen
    
    newPosition_f = FreqEnc.read();                     // lees de freq encoder rotatie
    // Freq verandering verwerken
    if (newPosition_f != oldPosition_f) {
      newPos2_f = oldPosition_f;
      oldPosition_f = newPosition_f;

      if (newPosition_f/4 < newPos2_f/4){
        FStepIndex ++;                                  // FStepIndex 1 omhoog
        if (FStepIndex > 8) {                           // bewaking grens FStepIndex en loopt rond
          FStepIndex = 0;
        }
      }
      if (newPosition_f/4 > newPos2_f/4){
        FStepIndex --;                                  // FStepIndex 1 omlaag
          if (FStepIndex < 0) {                         // bewaking grens FStepIndex en loopt rond
            FStepIndex = 8;
          }
      }
    }
  }      
  lcd.noBlink();                              // Hier kom je zodra de knop wordt ingedrukt, ga dan terug naar gewone cursor
  lcd.cursor();
  ExecFreq();
  FStep = FStepArray[FStepIndex];
  
  valFreq = analogRead(A2);
//  Serial.print("Fstep2  ");  // debug
//  Serial.println(valFreq);   // debug
  while (valFreq >= 120 && valFreq <= 165) {              //houd het programma hier vast tot knop weer los is. Daarna pas weer verder. Anders wordt de HamBand veranderd.
    valFreq = analogRead(A2);                             // blijven scannen binnen de while do
    delay(1);
  }
  delay(5);                                   // debounce 5ms
}
// --------------EINDE  FStep veranderen met rotary encoder - functie -----



// ------------- HamBand schakelen met druk knop van freq encoder - functie ---------
void HamBandFunctie(){
  HamBandIndex++;
  if (HamBandIndex>15) {
    HamBandIndex = 0;
  }
  Schermwaarde = HamBandArray[HamBandIndex];
  ExecFreq();
  delay (200);
}



// ------------------Zet freq in VFO en roept ook de Print Frequentie functie aan - functie -------
void ExecFreq() {

  Freq = 100 * Schermwaarde;                 // De freq gaat naar de VFO in hondersten van een Hz, daarom Schermwaarde x 100   
    if (Schermwaarde > 150000000ULL) {          // Schermwaarde hoger dan 150Mhz, deel door 3 en werk met 3e harmonische, dus Freq = 100/3 x Schermwaarde
    Freq = Freq / 3;
  } 
  si5351.set_freq(Freq, SI5351_CLK0);  // Stuurt Freq naar VFO, CLock 0
  PrintFreq();                               // Zet freq op display, zo volgt de display altijd de VFO freq.
}


// ---------------------- Print Freq op display ---------------------
void PrintFreq() {                   // Zet de Freq waarde keurig neer zonder leading zero's en met punt en komma op juiste plek
  unsigned long S;
  S = Schermwaarde;                  // hulp variable die stap voor stap wordt ontleed
  lcd.setCursor(4, 1);               // plaats cursus aan begin van getal

                                     // Op het scherm brengen gaat per 10-factor tegelijk, eenvoudig zichtbaar hieronder:
  int f1=S/100000000;                // eerst delen voor het aantal 100-den MHz en f1 vasthouden
  if (f1 <1){
    lcd.print(" ");                  // als onder de 100 MHz dan spatie afdrukken, onderdrukt dus leading zero.
  }
  else {
    lcd.print(S/100000000);          // er zijn een aantal 100-den MHz dus druk het aantal 100-den MHz af
  }
  S = S - ((S/100000000)*100000000); //trek de 100-den MHz van de waarde af
  
  if ((S/10000000 <1) && (f1<1)){    //zijn er geen 10-tallen MHz en was eerste getal een " "?
    lcd.print(" ");                  // druk dan weer een spatie een spatie. We onderdrukken zo
  }                                  // de tweede leading zero
  else {
    lcd.print(S/10000000);           // zo ja, druk het aantal 10-tallen Mhz af
  }
  S = S - ((S/10000000)*10000000);   // trek de 10-tallen MHz van de waarde af.
  
  lcd.print(S/1000000);              // druk enkele MHz af
  S = S - ((S/1000000)*1000000);     // trek de aantal MHz af van de waarde
  
  lcd.print(".");
  
  lcd.print(S/100000);               // 100-den kHz
  S = S - ((S/100000)*100000);      
  lcd.print(S/10000);                // 10 tallen kHz
  S = S - ((S/10000)*10000); 
  lcd.print(S/1000);                 // kHz 
  S = S - ((S/1000)*1000);        
  
  lcd.print(",");
  
  lcd.print(S/100);                  // 100-den Hz
  S = S - ((S/100)*100);
  lcd.print(S/10);                   // 10-tallen Hz
  S = S - ((S/10)*10); 
  lcd.print(S);                      // Hz-en
  lcd.print(" kHz");
 
 
  lcd.setCursor(Cursorpos[FStepIndex],1);
  lcd.cursor();                      //zet de underscore (cursor) weer aan op positie waar de wijzigingen worden gemaakt
  
}



// ----------------------- LeveldBm functies -------------------------------------------------------


// --------- functie --- Level 1 dB omhoog ---------------
void Level_UP() {        
  LeveldBm++;
  if (LeveldBm > 0){
    LeveldBm = 0;
  }
  ExecLeveldBm();  // stuur de de ATT en display aan
}


// --------- functie --- Level 1 dB omlaag --------------
void Level_DOWN() {
  LeveldBm--;
  if (LeveldBm < -150){ // voor de test doeleinden moet dit -150 zijn zodat we de verzwakker kunnnen ijken
    LeveldBm = -150;    // bij gewoon gebruik staat hier -140.
  }
  ExecLeveldBm();
}
  


// ---------- functie ---- roept de ATTSet functie aan die de verzwakker inschakelt, en drukt gewenste Level af op display
void ExecLeveldBm() {      
  ATTSet();                // zet de juiste ATT aan in de verzwakker.
  PrintLevel();            // print dBm niveau op display
}


void ATTSet() {             // schakel de ATT in op bepaalde waarde voor de gewenste output
  // Dit is de versie voor de test: 
  // noteren: gemeten Output vs Freq en LeveldBm van de Arduino om transfer functie te maken.
  digitalWrite(LE1, LOW); // zet fijnlatch of 0
  digitalWrite(LE2, LOW); // zet grote stappen latch op 0
  
  int total;
  int trapatt;
  int rest;
  int grof; // stuurt de grote stappen (= 4 chips tegelijk) minimale stapgrootte= 4 x 0,5 = 2 dB
  int fijn;  // stuurt de fijne stap = per dB
  // ----------------- hier komt de vertaling naar juiste geijkte Niveau
  total = -1* LeveldBm ;     // werk met positieve !!! HIER KOMT OOK DE CONVERSIE VAN LEVELDBM NAAR DE GEWENSTE VERZWAKKING VOLGENS POLYNOOM
  // ----------------- einde vertaling
  trapatt = total / 5; // hoeveel verzwakking per trap zou er moeten zijn? Er zijn 5 trappen
  rest = total - (5 * trapatt);
  grof = 2 * trapatt;  // schuif bitjes 1x op voor hele dBs
  fijn = 2 * trapatt;  //  schuif bitjes 1x op voor hele dBs
  if (rest == 0){   //iedere trap evenveel verzwakking en hele getallen
  ; // doe niks
  }
  if (rest == 1) { 
    fijn = fijn+2 ;  // fijn is 1 dB hoger want rest is 1, bitjes zijn 1x opgeschoven  vandaar +2
  }
  if (rest == 2) {
    grof = grof +1 ; // er komt zo 4 x 0,5 dB bij  (bij grof gaat alles in 4-voud)
  }
  if (rest == 3) {
    grof = grof + 1;  // 4 x 0,5 dB erbij in grof 
    fijn = fijn + 2;  // 1 dB erbij voor fijn
  }
  if (rest == 4) {
    grof = grof + 2;  // 4 x 1 dB erbij voor grof
  }
  
 
  SchrijfATT(grof);        // zet de data op de pinnen
  digitalWrite(LE2, HIGH); // Met de latch clock van 1ms wordt de waarde ingeklokt
  delay(1);
  digitalWrite(LE2, LOW);
  lcd.setCursor(7,0);      // schrijf de grof waarde op display = 2x de echte waarde
  lcd.print("  ");
  lcd.setCursor(7,0);  
  lcd.print(grof);
  
  SchrijfATT(fijn);        // zet de data op de pinnen
  digitalWrite(LE1, HIGH); // Met de latch clock van 1ms wordt de waarde ingeklokt
  delay(1);
  digitalWrite(LE1, LOW);
  lcd.setCursor(13,0);      // schrijf de fijn waarde op display = 2x de echte waarde
  lcd.print("  ");
  lcd.setCursor(13,0);  
  lcd.print(fijn);  

  
  //  transferfunctie wordt per apparaat gemaakt bij de ijking.
}
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
void loop() {

  // ----------------------Eerst Rotary encoder algorithme ---
      
  newPosition_f = FreqEnc.read();            // lees de freq encoder rotatie
  newPosition_L = LeveldBmEnc.read();        // lees de Level encoder rotatie

  // Eerst Freq verandering verwerken
  if (newPosition_f != oldPosition_f) {
    newPos2_f = oldPosition_f;
    oldPosition_f = newPosition_f;

    if (newPosition_f/4 > newPos2_f/4){
      VFO_UP();
    }
     if (newPosition_f/4 < newPos2_f/4){
      VFO_DOWN();
    }    
  }
  
  // Nu LeveldBm verandering verwerken
  if (newPosition_L != oldPosition_L) {
    newPos2_L = oldPosition_L;
    oldPosition_L = newPosition_L;

    if (newPosition_L/4 > newPos2_L/4){
      Level_UP();
    }
     if (newPosition_L/4 < newPos2_L/4){
      Level_DOWN();
    }    
  }


  
  // --------  Andere toetsen lezen en iets mee doen, in dit geval de FStep grootte veranderen. 
  

  teller = 0;
  valF = analogRead(A2);
 // Serial.print("teller =");    // debug
 // Serial.println(teller);
 // Serial.println(valF);
  
  while (valF >=120 && valF <= 165) {                  // waarde 125  als de knop wordt ingedrukt
    teller++ ;
    valF = analogRead(A2);                            // blijven scannen tijdens de while do
    delay(1);
  }
  if (teller >= 300){  // knop > 0,5 sec ingedrukt dan FStep instellen met de FStepFunctie
    HamBandFunctie();
  }
  if (teller > 1 && teller < 300) {   // knop <0,5 sec ingedrukt dan HamBand veranderen met HamBandFunctie
     FStepFunctie();
  }
  


// --- Lees Encoder druktoets LeveldBmEnc om Level te veranderen (schakelt o.a. S9, S9+40, enz)   
  if (analogRead(A2)<30) {
  //  Serial.println("level");  // debug
    Level++;
  
    if (Level>5) {
      Level = 0;
    }
    LeveldBm = LeveldBmArray[Level];
    ExecLeveldBm();
    delay (300);
  }


// ---------------- EEPROM SAVE ----------------
//  if (digitalRead(A7)==LOW) {
//    PUTEEPROM();
//    delay (300);
//  }

}
  


// ------------------------------------------------------------------------------------------------------------  
// -------------------------------------------- end loop ------------------------------------------------------    
// ------------------------------------------------------------------------------------------------------------


//--------------------------------------- FM en AM TRIALS -------------------------
/*
// FM deel: 6 stappen van 1 kHz omhoog en ook weer naar beneden 
  for (i=0; i <= 5; i++){
      Freq = Freq + 100000;
      si5351.set_freq(Freq, SI5351_PLL_FIXED, SI5351_CLK0);
  }
    for (i=0; i <= 5; i++){
      Freq = Freq - 100000;
      si5351.set_freq(Freq, SI5351_PLL_FIXED, SI5351_CLK0);
  }
*/

/*
  Amplitude variatie  -- AM trial  -- gebruiken we niet in deze FM trial.
  si5351.output_enable(SI5351_CLK0, 1); // zet clk0 aan ofuit, 0 = uit, 1 = aan
  si5351.drive_strength(SI5351_CLK0, SI5351_DRIVE_2MA);
//  delayMicroseconds(90);  
  si5351.drive_strength(SI5351_CLK0, SI5351_DRIVE_4MA);
 // delayMicroseconds(10);
 si5351.drive_strength(SI5351_CLK0, SI5351_DRIVE_6MA);
 // delayMicroseconds(20);
  si5351.drive_strength(SI5351_CLK0, SI5351_DRIVE_8MA);
//  delayMicroseconds(90);
 si5351.drive_strength(SI5351_CLK0, SI5351_DRIVE_6MA);
//  delayMicroseconds(10);
 si5351.drive_strength(SI5351_CLK0, SI5351_DRIVE_4MA);
//  delayMicroseconds(10);
  si5351.drive_strength(SI5351_CLK0, SI5351_DRIVE_2MA);
  //delayMicroseconds(20);
  si5351.output_enable(SI5351_CLK0, 0); // zet clk0 aan ofuit, 0 = uit, 1 = aan  
  //delayMicroseconds(20);
*/

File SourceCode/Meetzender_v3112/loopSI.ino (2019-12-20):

void loop()
{
  // ----------------------
  // Frequency Rotary encoder algorithme ---
  newPosition_f = FreqEnc.read();               // lees de freq encoder rotatie veranderd op interrupt
  newPosition_L = LeveldBmEnc.read();           // lees de Level encoder rotatie veranderd op interrupt
  //------------------------------------------------------------------------------------------------------
  // Freq verandering van Si5351 verwerken
  if (newPosition_f != oldPosition_f) {         // er is een rotatie verandering gezien
    newPos2_f = oldPosition_f;                  // sla nieuwe positie_waarde op
    oldPosition_f = newPosition_f;              // oude positie_waarde == nieuwe positie_waarde

    if (newPosition_f/4 < newPos2_f/4){         // als een volledige stap (4 veranderingen) dan 
      VFO_UP();
    }
    if (newPosition_f/4 > newPos2_f/4){         // < en > verwisselen = draairichting
      VFO_DOWN();
    }
  }    

  // ---------------------------------------------------------------------------------------------------
  // LeveldBm verandering verwerken
  if (newPosition_L != oldPosition_L) {         // er is een rotatie verandering gezien
    newPos2_L = oldPosition_L;                  // sla nieuwe positie_waarde op
    oldPosition_L = newPosition_L;              // oude positie_waarde == nieuwe positie_waarde

    if (newPosition_L/4 > newPos2_L/4){         // als een volledige stap (4 veranderingen) dan 
      Level_UP();                               //
    }
     if (newPosition_L/4 < newPos2_L/4){        //
      Level_DOWN();                             //
    }    
  }
  //-------------------------------------------------------------------------------------------------
  // Rotary-encoder pushbuttons Level / FStep 
 
  SwitchValue();                                     // Read Sw 1,2,3,6,7,8,9
  // --- Lees Encoder druktoets LeveldBmEnc om Level te veranderen (schakelt o.a. S9, S9+40, enz)  
  if (Sw == 1) {                                     // toetsWaarde = 1 .. Level toets
    Level++;                                         // LevelIndex een stap omhoog
    if (Level>5) {                                   // eind LevelArray
        Level = 0;                                   // terug naar start LevelArray
    }
    LeveldBm = LeveldBmArray[Level];                 // haal waarde uit LevelArray
    ExecLeveldBm();                                  // routine die verzwakker aanstuurt
    delay(100);                                      // settling time
    Sw = 0;                                          // toetsWaarde wordt 0
  }

  // Fstep 1/10/100/1k/10k/100k/1M/10M/100M/1G veranderen
  if (Sw == 3) {                                     // toetsWaarde = 3 .. Frequentie toets
    Sw = 0;                                          // toetsWaarde wordt 0
    FStepFunctie();                                  // Fstep instellen
  }
  //----------------------------------------------------------------------------------------------------

    if (Sw == 6){                                     // Store this freq
     Sw = 0;
     digitalWrite(A4,HIGH);                           // Led S6 aan
     EEpromString = "Store this frequency";
     lcd.setCursor(0,1);
     lcd.print(EEpromString);
     PUTEEPROM();
     delay(2500);
     lcd.setCursor(0,1);
     lcd.print(F("                    "));
     digitalWrite(A4,LOW);                            // Led S6 weer uit
  }


  if (Sw == 7){                                       // Get Stored freq
     Sw = 0;
     digitalWrite(A5,HIGH);                           // Led S7 aan
     EEpromString = "Get stored frequency";
     lcd.setCursor(0,1);
     lcd.print(EEpromString);
     //if (Sw==7) 
     GETEEPROM();
     delay(2500);
     ExecFreq();
     ExecLeveldBm();
     lcd.setCursor(0,1);
     lcd.print(F("                    "));
     digitalWrite(A5,LOW);                            // Led S7 weer uit
  }

    // ************* hamband ****************************************
  if (Sw == 8){                                       // Ham Band menu
     Sw = 0;                                          // geen toets 
     digitalWrite(A6,HIGH);                           // Led S8 aan
     HamBandFunctie();                                //
     digitalWrite(A6,LOW);                            // Led S8 weer uit
  }
  
  if (Sw==9 ) { //&& resettijd < 1500) {  // als S9 <3 seconden ingedrukt dan calibratie menu
     //if (resettijd > 1) Serial.println (resettijd);
     Sw = 0;
     digitalWrite(A7,HIGH);                           // HF ledje weer aan
     calibratieMenu();
     digitalWrite(A7,LOW);                            // HF led weer uit
  } 
  
  lcd.setCursor(Cursorpos[FStepIndex],0);             // plaats cursor onder aktieve frequentie digit
  lcd.cursor();                                       // toon underscore cursor
}

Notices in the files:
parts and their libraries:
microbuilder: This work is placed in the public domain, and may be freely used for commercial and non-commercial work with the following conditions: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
